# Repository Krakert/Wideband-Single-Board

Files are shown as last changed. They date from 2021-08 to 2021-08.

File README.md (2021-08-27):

# Wideband-Single-Board
This is a redesigned pcb, based on the work of [mck1117](https://github.com/mck1117 "mck1117").
For the original design see [this repo.](https://github.com/mck1117/wideband)

# changes to the board
* just a 2 layer board instead of 4.
* Used of a more commonly available main connector [MX23A12NF1](https://www.jae.com/en/connectors/series/detail/product/id=64755&type_code=T1040), 
can be found on [Aliexpress](https://www.aliexpress.com/item/1005001800960426.html?product_id=1005001800960426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).



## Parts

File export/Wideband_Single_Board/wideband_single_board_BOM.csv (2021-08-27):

Comment | Designator | Footprint | LCSC
1u | C10,C11,C15 | Capacitor_SMD:C_0603_1608Metric | C15849
22u | C13 | Capacitor_SMD:C_0805_2012Metric | C45783
100n | C2,C12,C14,C20,C22,C23,C24,C26 | Capacitor_SMD:C_0402_1005Metric | C1525
47p | C18,C19 | Capacitor_SMD:C_0402_1005Metric | C1567
1u | C1,C8,C16,C17,C21 | Capacitor_SMD:C_0402_1005Metric | C52923
DNP | C25,C27 | Capacitor_SMD:C_0402_1005Metric
10u | C3,C6,C7,C9 | Capacitor_SMD:C_1206_3216Metric | C13585
4.7u | C4 | Capacitor_SMD:C_0603_1608Metric | C19666
33n | C5 | Capacitor_SMD:C_0402_1005Metric | C1585
D_TVS | D1 | Diode_SMD:D_SMC | C151279
RED | D2,D6 | LED_SMD:LED_0603_1608Metric | C2286
D_Schottky | D3 | Diode_SMD:D_SMA | C22452
BLUE | D4 | LED_SMD:LED_0603_1608Metric | C72041
GREEN | D5 | LED_SMD:LED_0603_1608Metric | C72043
Conn_02x05_Top_Bottom | J1 | TestPoint:Solder_pad_5X2X3.0X2.0mm
USB_B_Micro | J2 | Connector_USB:USB_Micro-B_Molex-105017-0001 | C404969
Conn_02x04_Top_Bottom | J3 | Connector_PinHeader_2.54mm:PinHeader_2x04_P2.54mm_Vertical
Jumper_3_Open | JP1,JP2 | Jumper:SolderJumper-3_P1.3mm_Open_Pad1.0x1.5mm
BTS3028 | Q1 | Package_TO_SOT_SMD:TO-252-2 | C112639
61.9 | R10 | Resistor_SMD:R_0603_1608Metric | C23092
100k | R13,R14 | Resistor_SMD:R_0402_1005Metric | C25741
22k | R18 | Resistor_SMD:R_0402_1005Metric | C25768
3.3k | R19 | Resistor_SMD:R_0402_1005Metric | C25890
27k | R17,R20 | Resistor_SMD:R_0402_1005Metric | C25771
20k | R21,R22,R25 | Resistor_SMD:R_0402_1005Metric | C25765
220 | R23 | Resistor_SMD:R_0603_1608Metric | C22962
470 | R24 | Resistor_SMD:R_0603_1608Metric | C23179
1k | R1,R2,R9,R26,R27,R29,R30,R31 | Resistor_SMD:R_0402_1005Metric | C11702
10k | R5,R6,R11,R12,R15,R16,R28 | Resistor_SMD:R_0402_1005Metric | C25744
68k | R3,R4 | Resistor_SMD:R_0402_1005Metric | C36871
10 | R7 | Resistor_SMD:R_0402_1005Metric | C25077
47 | R8 | Resistor_SMD:R_0402_1005Metric | C25118
SW_Push | SW1 | lib_wideband_sigle_board:TS1088R02026 | C720477
XC6206P332MR | U1 | Package_TO_SOT_SMD:SOT-23 | C5446
MCP6004 | U2 | Package_SO:TSSOP-14_4.4x5mm_P0.65mm | C50282
LM78M05_TO252 | U3 | Package_TO_SOT_SMD:TO-252-2 | C58069
AD8628 | U4 | Package_TO_SOT_SMD:TSOT-23-5 | C29309
TJA1051T-3 | U5 | Package_SO:SOIC-8_3.9x4.9mm_P1.27mm | C38695
REF3033 | U6 | Package_TO_SOT_SMD:SOT-23 | C36658
STM32F042K6Tx | U7 | Package_QFP:LQFP-32_7x7mm_P0.8mm | C69216

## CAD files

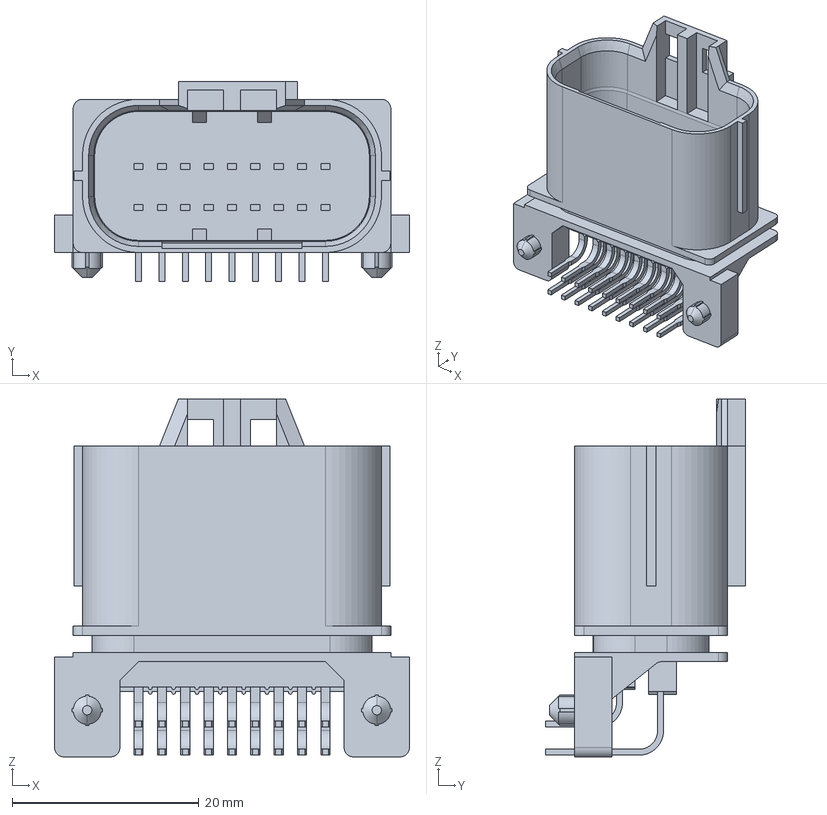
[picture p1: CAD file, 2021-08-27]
lib_wideband_sigle_board/MX23A18NF1.stp
38.0 x 21.4 x 38.3 mm

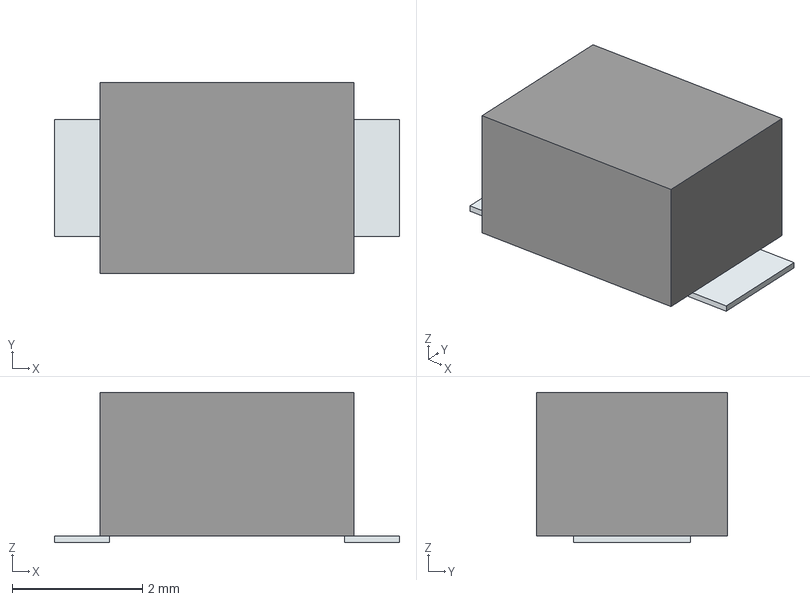
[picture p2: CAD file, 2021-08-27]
lib_wideband_sigle_board/TS-1088R-02026.stp
5.29 x 2.93 x 2.30 mm
Pins

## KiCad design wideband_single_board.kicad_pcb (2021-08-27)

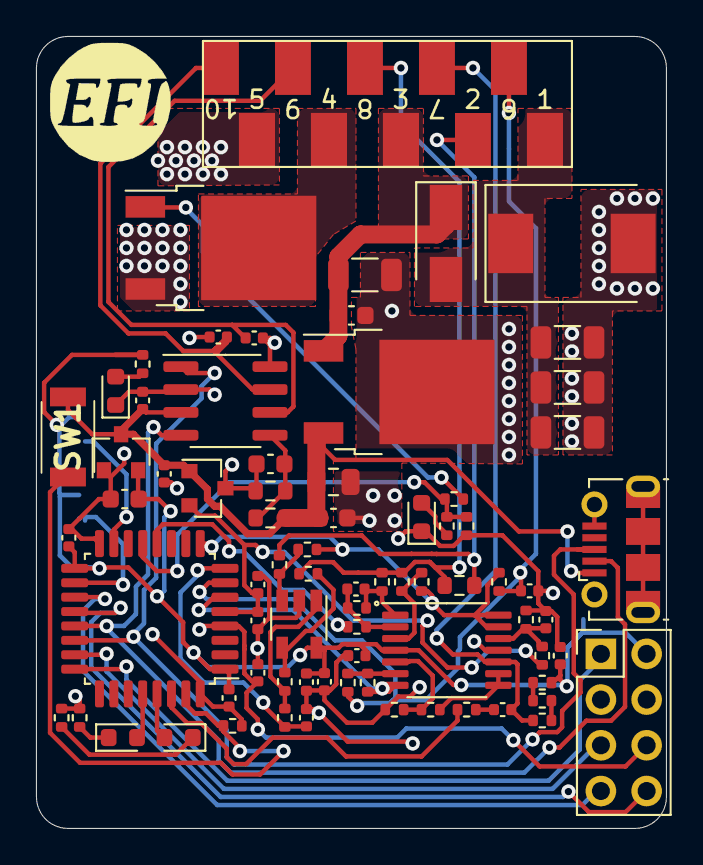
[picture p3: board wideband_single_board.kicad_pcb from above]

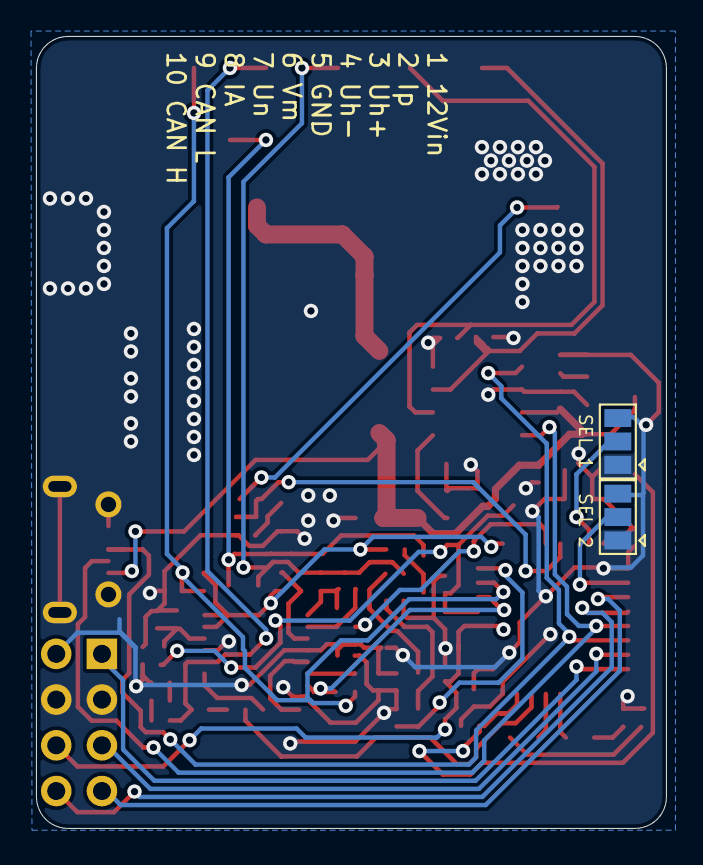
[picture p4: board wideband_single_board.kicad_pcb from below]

Board: 2 copper layers, 35.0 x 44.0 mm, 79 parts (2 on the bottom side), 50 nets.

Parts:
C1, C8, C16, C17, C21: 1u; C_0402_1005Metric
C2, C12, C14, C20, C22, C23, C24, C26: 100n; C_0402_1005Metric
C3, C6, C7, C9: 10u; C_1206_3216Metric
C4: 4.7u; C_0603_1608Metric
C5: 33n; C_0402_1005Metric
C10, C11, C15: 1u; C_0603_1608Metric
C13: 22u; C_0805_2012Metric
C18, C19: 47p; C_0402_1005Metric
C25, C27: DNP; C_0402_1005Metric
D1: D_TVS; D_SMC
D2, D6: RED; LED_0603_1608Metric
D3: D_Schottky; D_SMA
D4: BLUE; LED_0603_1608Metric
D5: GREEN; LED_0603_1608Metric
G?: LOGO
J1: Conn_02x05_Top_Bottom; Solder_pad_5X2X3.0X2.0mm
J2: USB_B_Micro; USB_Micro-B_Molex-105017-0001
J3: Conn_02x04_Top_Bottom; PinHeader_2x04_P2.54mm_Vertical
JP1, JP2: Jumper_3_Open; SolderJumper-3_P1.3mm_Open_Pad1.0x1.5mm
Q1: BTS3028; TO-252-2
R1, R2, R9, R26, R27, R29, R30, R31: 1k; R_0402_1005Metric
R3, R4: 68k; R_0402_1005Metric
R5, R6, R11, R12, R15, R16, R28: 10k; R_0402_1005Metric
R7: 10; R_0402_1005Metric
R8: 47; R_0402_1005Metric
R10: 61.9; R_0603_1608Metric
R13, R14: 100k; R_0402_1005Metric
R17, R20: 27k; R_0402_1005Metric
R18: 22k; R_0402_1005Metric
R19: 3.3k; R_0402_1005Metric
R21, R22, R25: 20k; R_0402_1005Metric
R23: 220; R_0603_1608Metric
R24: 470; R_0603_1608Metric
SW1: SW_Push; TS1088R02026
U1: XC6206P332MR; SOT-23
U2: MCP6004; TSSOP-14_4.4x5mm_P0.65mm
U3: LM78M05_TO252; TO-252-2
U4: AD8628; TSOT-23-5
U5: TJA1051T-3; SOIC-8_3.9x4.9mm_P1.27mm
U6: REF3033; SOT-23
U7: STM32F042K6Tx; LQFP-32_7x7mm_P0.8mm

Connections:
12V_RAW: C3.1, C6.2, C7.1, D1.1, D3.2, J1.1
+3V3: C4.1, C22.1, C23.1, C24.1, C25.1, C26.1, C27.1, J3.2, JP1.3, JP2.3, R9.2, R25.1, U1.2, U2.4, U4.5, U7.1, U7.17
+5V: C2.1, C11.1, C13.1, C16.1, J2.1, R23.1, SW1.2, U1.3, U3.3, U5.3, U6.1
/Boot0: R28.2, SW1.1, U7.31
/CAN_H: C18.2, J1.10, U5.7
/CAN_L: C19.1, J1.9, U5.6
/CAN_RX: J2.2, U5.4, U7.21
/CAN_TX: J2.3, U5.1, U7.22
/Ip_dac: R3.1, U7.12
/Ip_sense: C14.1, R19.2, U7.8
/LED_BLUE: D4.2, U7.28
/LED_GREEN: D5.2, U7.29
/LSU_Heater+: C9.1, C10.1, D3.1, J1.3, U3.1
/LSU_Heater-: J1.4, Q1.2
/LSU_Ip: J1.2, R10.2, R12.2
/LSU_Rtrim: J1.8, R6.1, R8.1, R10.1, R11.2
/LSU_Un: C12.1, J1.7, R21.1, U2.10
/LSU_Un_sense: R16.1, U2.8, U2.9
/LSU_Vm: C8.1, J1.6, R7.1, R15.1, U7.7
/Nernst_esr_drive: R18.1, U7.30
/SEL_1: JP1.2, U7.15
/SEL_2: JP2.2, U7.18
/SWCLK: J3.1, U7.24
/SWDIO: J3.5, U7.23
/UART_RX: J3.8, U7.20
/UART_TX: J3.7, U7.19
/Un_sense: R20.2, U2.7, U7.6
/Vm: R4.2, R7.2, R13.2, U2.13, U2.14, U7.9
/heater_pwm: R29.2, R30.2, R31.2, U7.13
/nRESET: C21.1, J3.6, U7.4
GND: C1.2, C2.2, C3.2, C4.2, C6.1, C7.2, C8.2, C9.2, C10.2, C11.2, C13.2, C14.2, C15.2, C16.2, C17.2, C18.1, C19.2, C20.2, C21.2, C22.2, C23.2, C24.2, C25.2, C26.2, C27.2, D1.2, D2.1, D6.1, J1.5, J2.5, J2.6, J3.3, J3.4, JP1.1, JP2.1, Q1.3, R2.2, R17.2, R24.2, R26.1, R27.1, R28.1, R30.1, U1.1, U2.11, U3.2, U4.2, U5.2, U5.8, U6.3, U7.16, U7.32
unnamed: C1.1, R1.2, R2.1, U2.12
unnamed: C5.1, R5.1, R8.2, U2.1
unnamed: C5.2, R3.2, R5.2, U2.2
unnamed: C12.2, R18.2
unnamed: C15.1, R23.2, R24.1, U5.5
unnamed: D2.2, R9.1
unnamed: D4.1, R26.2
unnamed: D5.1, R27.2
unnamed: D6.2, R29.1
unnamed: Q1.1, R31.1
unnamed: R4.1, R6.2, U2.3
unnamed: R11.1, R14.2, U4.4
unnamed: R12.1, R13.1, U4.3
unnamed: R14.1, R19.1, U4.1
unnamed: R15.2, R20.1, U2.6
unnamed: R16.2, R17.1, U2.5
unnamed: R21.2, R22.2
unnamed: R22.1, R25.2
VDDA: C17.1, C20.1, R1.1, U6.2, U7.5

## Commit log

2021-08-25 first init kicad files
    [MX23A12NF1.step, wideband_2.0.kicad_pcb, wideband_2.0.sch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]
2021-08-25 rename project
    [MX23A12NF1.step, wideband_2.0.kicad_pcb, wideband_2.0.sch]
2021-08-27 changed overall layout of the board and made a connector board to wire up two LSU4.9 to 2 board in a single case
    [MX23A12NF1.step, MX23A18NF1.stp, TS-1088R-02026.stp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]
